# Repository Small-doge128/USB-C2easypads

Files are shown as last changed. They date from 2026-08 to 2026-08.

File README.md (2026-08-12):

# About
A really small, compact and simple USB-C PCB with 2 output pads and of course USB-C (16pin). It's for 12V (47k resistor), but if you want higher voltage, buy a different Rset resistor, TVS diodes and fuse.

# features
USB-C 16 pin, 2 output pads, 4 resistors, 1 poly fuse, CH221K for higher voltage, 10uf capacitor and 100nf capacitor. All bundled up on a small PCB that I designed in Kicad. If you want you can have higher voltage or lower, all you need to do is change the fuse, TVS diodes and Rset resistor. The target voltage can be easily set by a table on the back of the PCB and a arrow pointing to the Rset resistor.

# dimensions
PCB - 22.75 mm x 10.75 mm

# why did I create it
I wanted a way to convert my soldering iron to USB-C for better usability, so I thought why not make it for more use and for more people, so that's how it was created.

# pictures









# BOM

| Name | Purpose | Qty | Price (USD) | Distributor | Link |
| :--- | :--- | :---: | :---: | :--- | :--- |
| PCB | for conecting all of the parts | 5 | $ 5 | PCBWAY | [Link](https://pcbway.com) |
| CH221K chip | for drawing more power from the USB-C | 5 | $ 1.65 | LCSC | [Link](https://www.lcsc.com/product-detail/C5125736.html) |
| TVS diode | for protection | 10 | $ 0.06 | LCSC | [Link](https://www.lcsc.com/product-detail/C7018346.html) |
| polyfuse | for protecting all of the parts from over-current / short circuits | 20 | $ 0.69 | LCSC | [Link](https://www.lcsc.com/product-detail/C42449089.html) |
| 47kΩ resistor | for drawing the requested voltage | 100 | $ 1.31 | LCSC | [Link](https://www.lcsc.com/product-detail/C17713.html) |
| 1kΩ resistor | protection | 100 | already at home | LCSC | [Link](https://www.lcsc.com/product-detail/C84375.html) |
| 5.1kΩ resistor | protection | 200 | already at home | LCSC | [Link](https://www.lcsc.com/product-detail/C95781.html) |
| 10uf capacitor | protection | 100 | already at home | LCSC | [Link](https://www.lcsc.com/product-detail/C13585.html) |
| 100nf capacitor | protection | 100 | already at home | LCSC | [Link](https://www.lcsc.com/product-detail/C49678.html) |
| **TOTAL without shipping and taxes** | | | **$ 8.71** | | |
| **TOTAL with shipping and taxes** | | | **$ 43** | | |

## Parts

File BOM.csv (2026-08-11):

Name | Purpose | Qty | Price (USD) | Distributor | Link
PCB | for conecting all of the parts | 5 | $ 5 | PCBWAY | https://pcbway.com
CH221K chip | for drawing more power from the USB-C | 5 | $ 1.65 | LCSC | https://www.lcsc.com/product-detail/C5125736.html
TVS diode | for protection | 10 | $ 0.06 | LCSC | https://www.lcsc.com/product-detail/C7018346.html
polyfuse | for protecting all of the parts from over-current / short circuits | 20 | $ 0.69 | LCSC | https://www.lcsc.com/product-detail/C42449089.html
47kΩ resistor | for drawing the requested voltage | 100 | $ 1.31 | LCSC | https://www.lcsc.com/product-detail/C17713.html
1kΩ resistor | protection | 100 | already at home | LCSC | https://www.lcsc.com/product-detail/C84375.html
5.1kΩ resistor | protection | 200 | already at home | LCSC | https://www.lcsc.com/product-detail/C95781.html
10uf capacitor | protection | 100 | already at home | LCSC | https://www.lcsc.com/product-detail/C13585.html
100nf capacitor | protection | 100 | already at home | LCSC | https://www.lcsc.com/product-detail/C49678.html
TOTAL without shipping and taxes |  |  | $ 8.71
TOTAL with shipping and taxes |  |  | $ 43

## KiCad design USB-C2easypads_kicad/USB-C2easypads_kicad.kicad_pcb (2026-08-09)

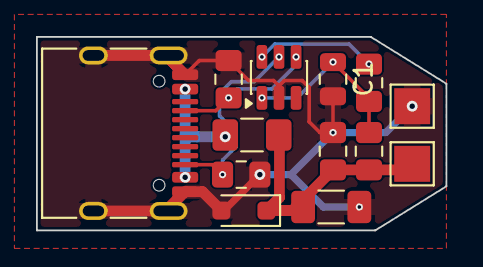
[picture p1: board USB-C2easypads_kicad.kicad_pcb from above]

Board: 2 copper layers, 22.8 x 10.8 mm, 13 parts (0 on the bottom side), 7 nets.

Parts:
C1: C_Small; C_0805_2012Metric
C2: C_Small; C_0805_2012Metric_Pad1.18x1.45mm_HandSolder
C3: C_Small; C_1206_3216Metric_Pad1.33x1.80mm_HandSolder
D1: HSD12C; D_SOD-323_HandSoldering
F1: 3A; Fuse_1206_3216Metric_Pad1.42x1.75mm_HandSolder
J1: USB_C_Receptacle_USB2.0_16P; USB_C_Receptacle_HRO_TYPE-C-31-M-12
J2, J3: Conn_01x01_Pin; TestPoint_Pad_2.0x2.0mm
R2, R3, R4, R5: R; C_0805_2012Metric_Pad1.18x1.45mm_HandSolder
U1: CH221K; SOT-23-6

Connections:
/CC1: J1.A5 (CC1), R4.2, U1.4 (CC1)
/CC2: J1.B5 (CC2), R5.2, U1.5 (CC2)
/USB_VBUS: F1.1, J1.A4 (VBUS), J1.A9 (VBUS), J1.B4 (VBUS), J1.B9 (VBUS)
GND: C1.2, C2.1, C3.2, D1.2 (A), J1.A1 (GND), J1.A12 (GND), J1.B1 (GND), J1.B12 (GND), J1.SH (SHIELD), J2.1 (Pin_1_1), R4.1, R5.1, U1.2 (GND)
unnamed: R2.1, U1.6 (CFG)
unnamed: C1.1, R2.2, R3.1, U1.1 (VDD)
VBUS: C2.2, C3.1, D1.1 (K), F1.2, J3.1 (Pin_1_1), R3.2
